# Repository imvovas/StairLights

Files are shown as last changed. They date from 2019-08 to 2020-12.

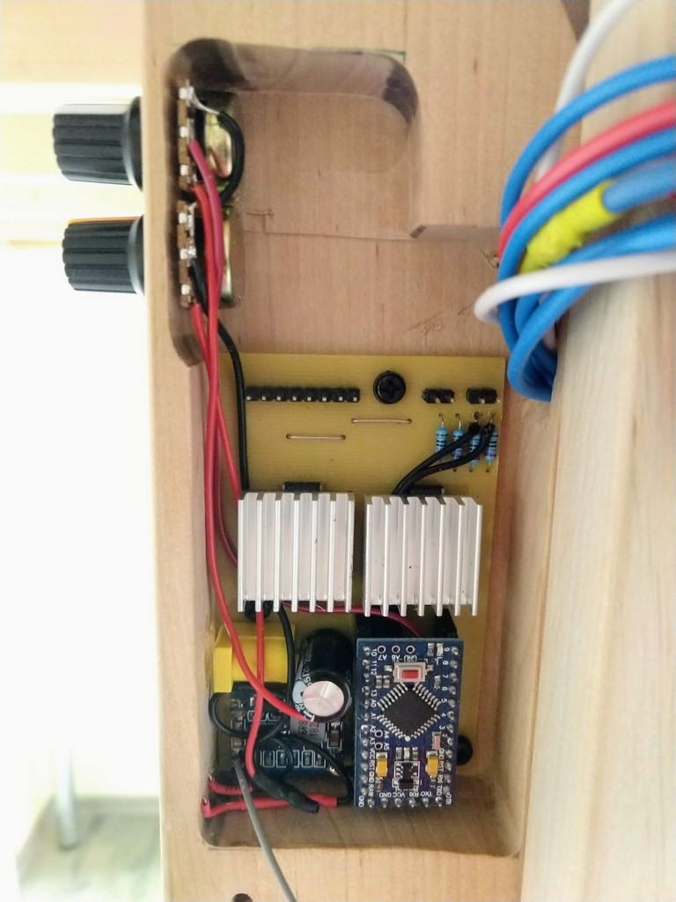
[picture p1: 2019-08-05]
photos/IMG_20190805_171643290.jpg

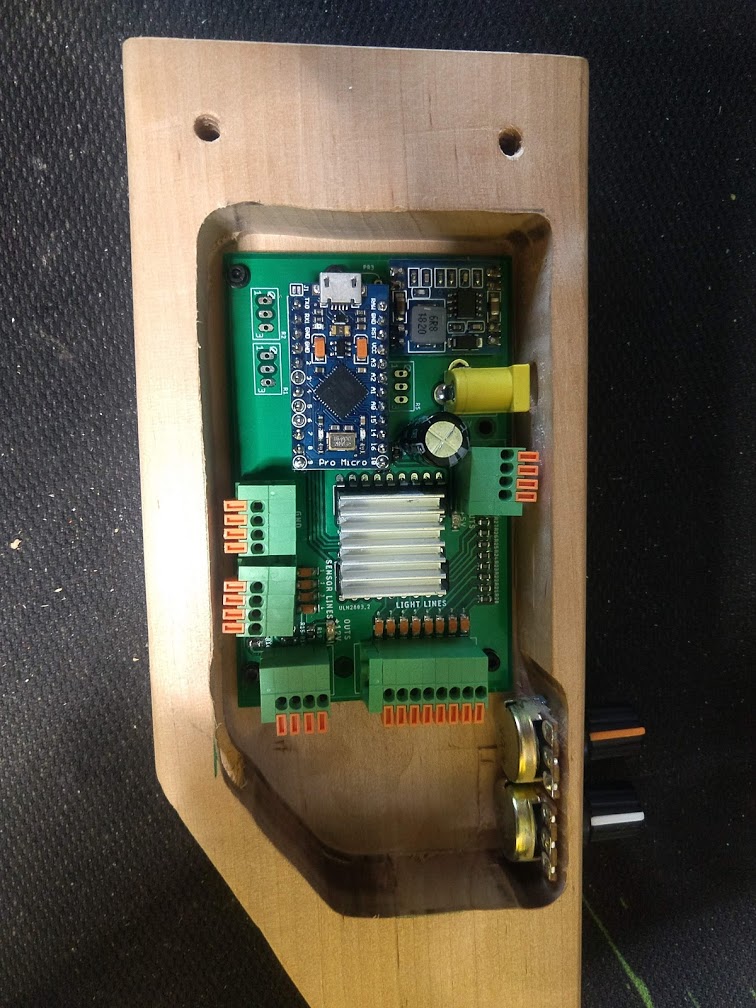
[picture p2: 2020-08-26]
photos/IMG_20200605_162837058.jpg

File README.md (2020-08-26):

# StairLights
Програмно-аппаратный комплект StairLights

Код для управления Arduino Leonardo (китайский клон)

В коде прошивки добавлены:
* управление скоростью отработки эффектов через подстроечный резистор;
* удалена поддержка кнопок вместе с библиотекой подавления дребезга;
* исправлены ошибки в визуальных эффектах.

Аппаратная часть находится в папке /Board. Актуальная версия платы в архиве StairLights_clips_2020-08-26.zip.
В актуальной редакции платы добавлены:
* дополнительные выводы 12 Вольт, 5 Вольт;
* добавлено два входа для сенсоров;
* добавлены отладочные светодиоды.
* Плата переведена на двухсторонний монтаж и под фабричное изготовление.

Ограничения:
- Напряжение питания устройства - 12 Вольт.
- Для питания Arduino Leonardo (китайский клон) использован DC-DC преобразователь (7-24 Вольта - 5 Вольт).
- Управляющие выходы подключаются к 8 сегментам LED-ленты 12 Вольт и потребляемой мощностью не более 500 мА на один сегмент.
- Используются управляющие сигналы TTL-уровня, при отсутствии сигнала входы притянуты к "земле".
- В качестве сенсоров можно использовать любые датчики/выключатели при условия соблюдения TTL-уровней сигнала. В коде прошивки реализована логика с поддержкой двух входов из четырех.

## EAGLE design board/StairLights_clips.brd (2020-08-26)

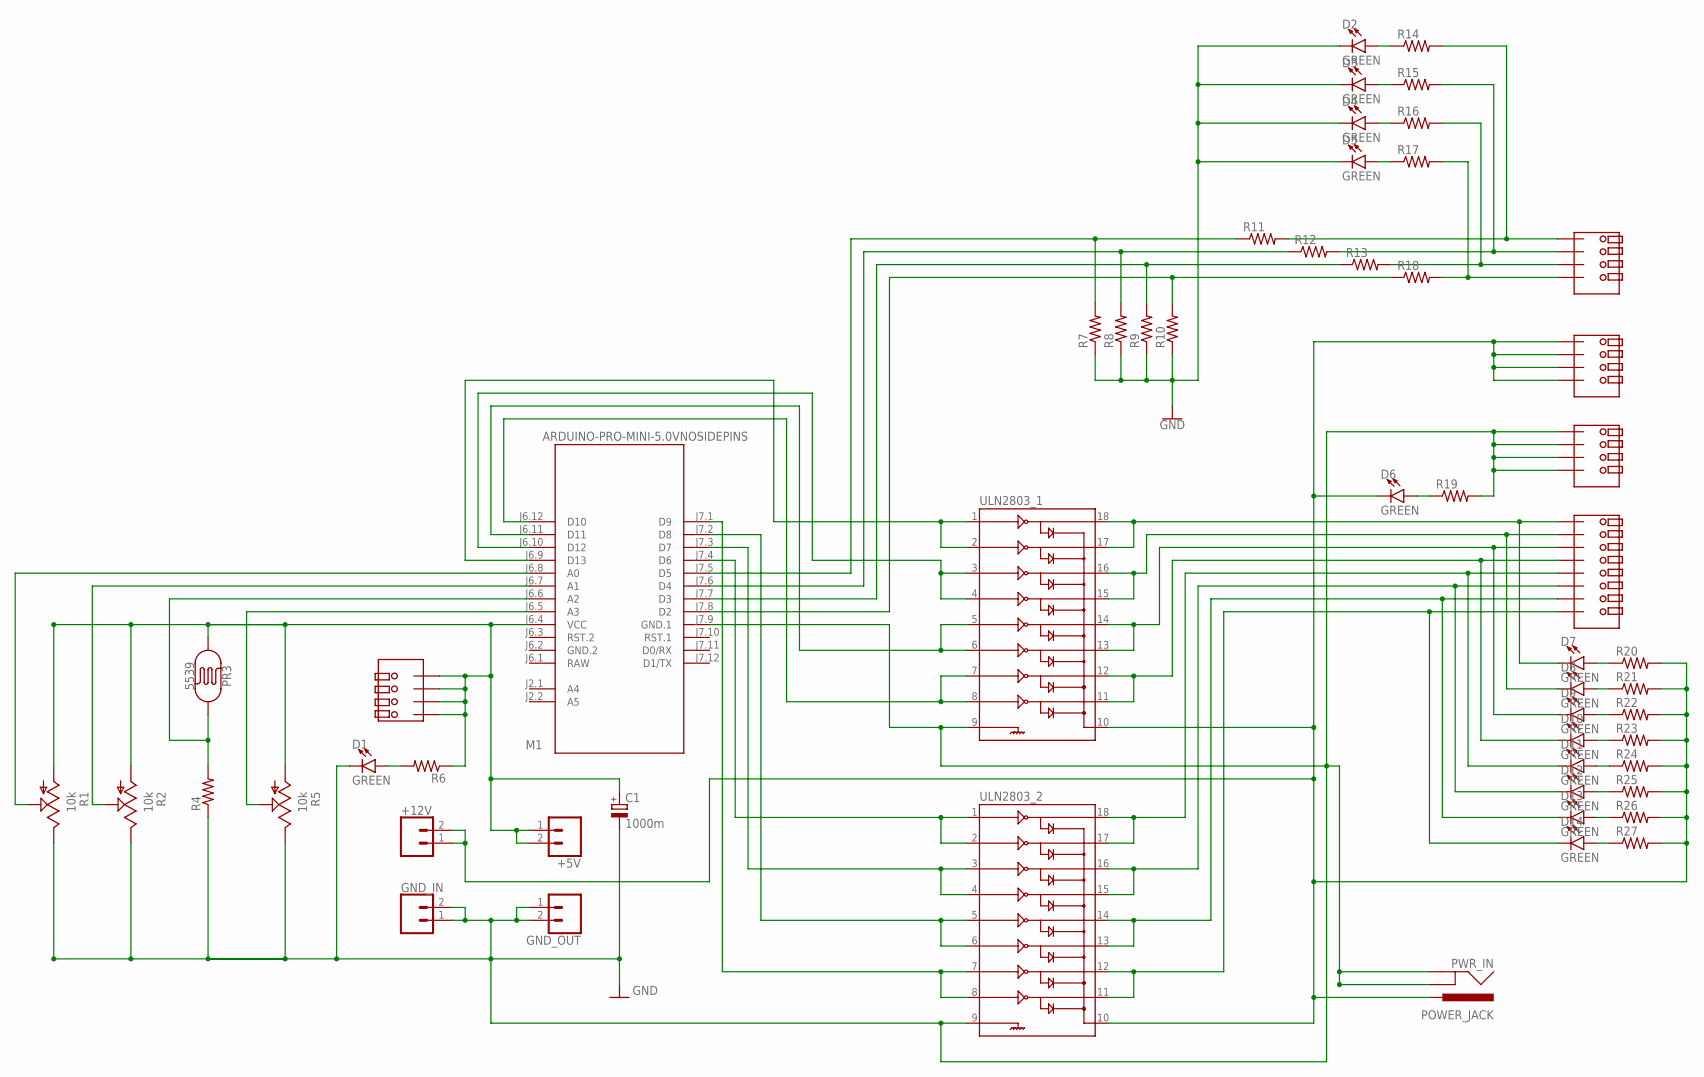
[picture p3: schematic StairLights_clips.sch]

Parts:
+5V, +12V: CONN_02; 1X02
C1: 1000m; E5-5
D1, D2, D3, D4, D5, D6, D7, D8, D9, D10, D11, D12, D13, D14: GREEN; LED-1206
GND_IN: CONN_02; 1X02
GND_OUT: CONN_02; 1X02
M1: ARDUINO-PRO-MINI-5.0VNOSIDEPINS; ARDUINO-PRO-MINI
PR3: 5539; PHOTOCELL
PWR_IN: POWER_JACK; POWER_JACK_PTH
R1, R2, R5: 10k; S64W
R4, R7, R8, R9, R10: 10k; R0805
R6, R11, R12, R13, R14, R15, R16, R17, R18, R19, R20, R21, R22, R23, R24, R25, R26, R27: 330; R0805
SC1, SC2, SC3, SC4: KF141V-4
SC5: KF141V-8
ULN2803_1, ULN2803_2: ULN2803DIP; DIL18

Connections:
GND: C1.-, D1.C, D2.C, D3.C, D4.C, D5.C, GND_IN.1, GND_IN.2, GND_OUT.1, GND_OUT.2, M1.J7.9 (GND.1), PWR_IN.GND, PWR_IN.GNDBREAK, R1.E, R2.E, R4.1, R5.E, R7.1, R8.1, R9.1, R10.1, R19.2, SC4.P$1, SC4.P$2, SC4.P$3, SC4.P$4, SC4.P$9, SC4.P$10, SC4.P$11, SC4.P$12, ULN2803_1.9, ULN2803_2.9
GND.2: M1.J6.2 (GND.2)
unnamed: D7.C, SC5.P$1, SC5.P$9, ULN2803_1.17, ULN2803_1.18
unnamed: D8.C, SC5.P$2, SC5.P$10, ULN2803_1.15, ULN2803_1.16
unnamed: M1.J7.7 (D3), R9.2, R13.1
unnamed: D9.C, SC5.P$3, SC5.P$11, ULN2803_1.13, ULN2803_1.14
unnamed: M1.J6.12 (D10), ULN2803_1.7, ULN2803_1.8
unnamed: D10.C, SC5.P$4, SC5.P$12, ULN2803_1.11, ULN2803_1.12
unnamed: M1.J6.6 (A2), PR3.2, R4.2
unnamed: D11.C, SC5.P$5, SC5.P$13, ULN2803_2.17, ULN2803_2.18
unnamed: D12.C, SC5.P$6, SC5.P$14, ULN2803_2.15, ULN2803_2.16
unnamed: M1.J6.11 (D11), ULN2803_1.5, ULN2803_1.6
unnamed: D13.C, SC5.P$7, SC5.P$15, ULN2803_2.13, ULN2803_2.14
unnamed: M1.J7.8 (D2), R10.2, R18.1
unnamed: M1.J7.3 (D7), ULN2803_2.3, ULN2803_2.4
unnamed: R13.2, R16.2, SC2.P$3, SC2.P$11
unnamed: M1.J6.5 (A3), R5.S
unnamed: D1.A, R6.2
unnamed: +5V.1, +5V.2, C1.+, M1.J6.4 (VCC), PR3.1, R1.A, R2.A, R5.A, R6.1, SC1.P$1, SC1.P$2, SC1.P$3, SC1.P$4, SC1.P$9, SC1.P$10, SC1.P$11, SC1.P$12
unnamed: D14.C, SC5.P$8, SC5.P$16, ULN2803_2.11, ULN2803_2.12
unnamed: R17.2, R18.2, SC2.P$4, SC2.P$12
unnamed: M1.J7.6 (D4), R8.2, R12.1
unnamed: M1.J7.1 (D9), ULN2803_2.7, ULN2803_2.8
unnamed: M1.J7.5 (D5), R7.2, R11.1
unnamed: R12.2, R15.2, SC2.P$2, SC2.P$10
unnamed: M1.J6.9 (D13), ULN2803_1.1, ULN2803_1.2
unnamed: R11.2, R14.2, SC2.P$1, SC2.P$9
unnamed: M1.J6.10 (D12), ULN2803_1.3, ULN2803_1.4
unnamed: M1.J6.7 (A1), R2.S
unnamed: M1.J6.8 (A0), R1.S
unnamed: M1.J7.4 (D6), ULN2803_2.1, ULN2803_2.2
unnamed: M1.J7.2 (D8), ULN2803_2.5, ULN2803_2.6
unnamed: D7.A, R20.1
unnamed: D8.A, R21.1
unnamed: D9.A, R22.1
unnamed: D10.A, R23.1
unnamed: D11.A, R24.1
unnamed: D12.A, R25.1
unnamed: D13.A, R26.1
unnamed: D14.A, R27.1
unnamed: +12V.1, +12V.2, D6.C, PWR_IN.PWR, R20.2, R21.2, R22.2, R23.2, R24.2, R25.2, R26.2, R27.2, SC3.P$1, SC3.P$2, SC3.P$3, SC3.P$4, SC3.P$9, SC3.P$10, SC3.P$11, SC3.P$12, ULN2803_1.10, ULN2803_2.10
unnamed: D6.A, R19.1
unnamed: D2.A, R14.1
unnamed: D3.A, R15.1
unnamed: D4.A, R16.1
unnamed: D5.A, R17.1
RAW: M1.J6.1 (RAW)

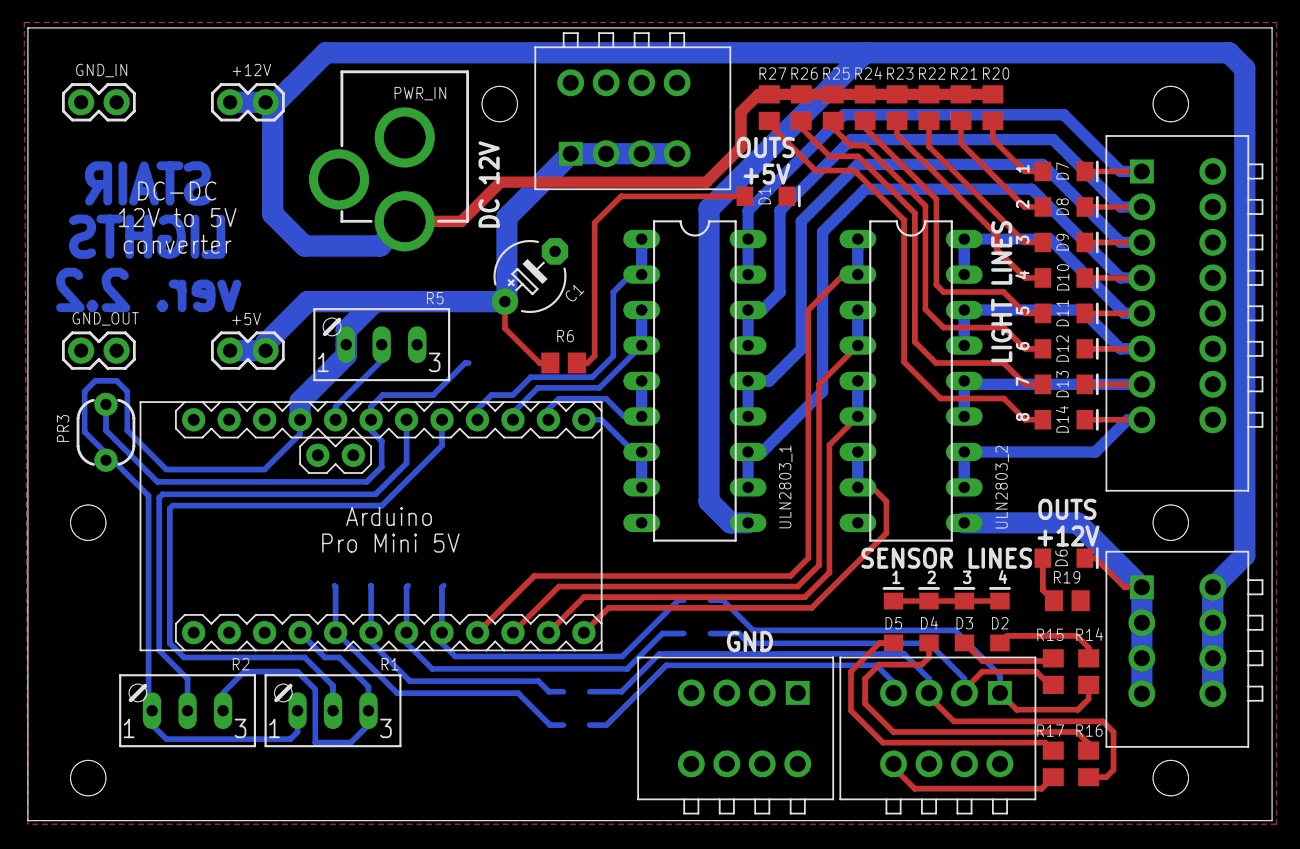
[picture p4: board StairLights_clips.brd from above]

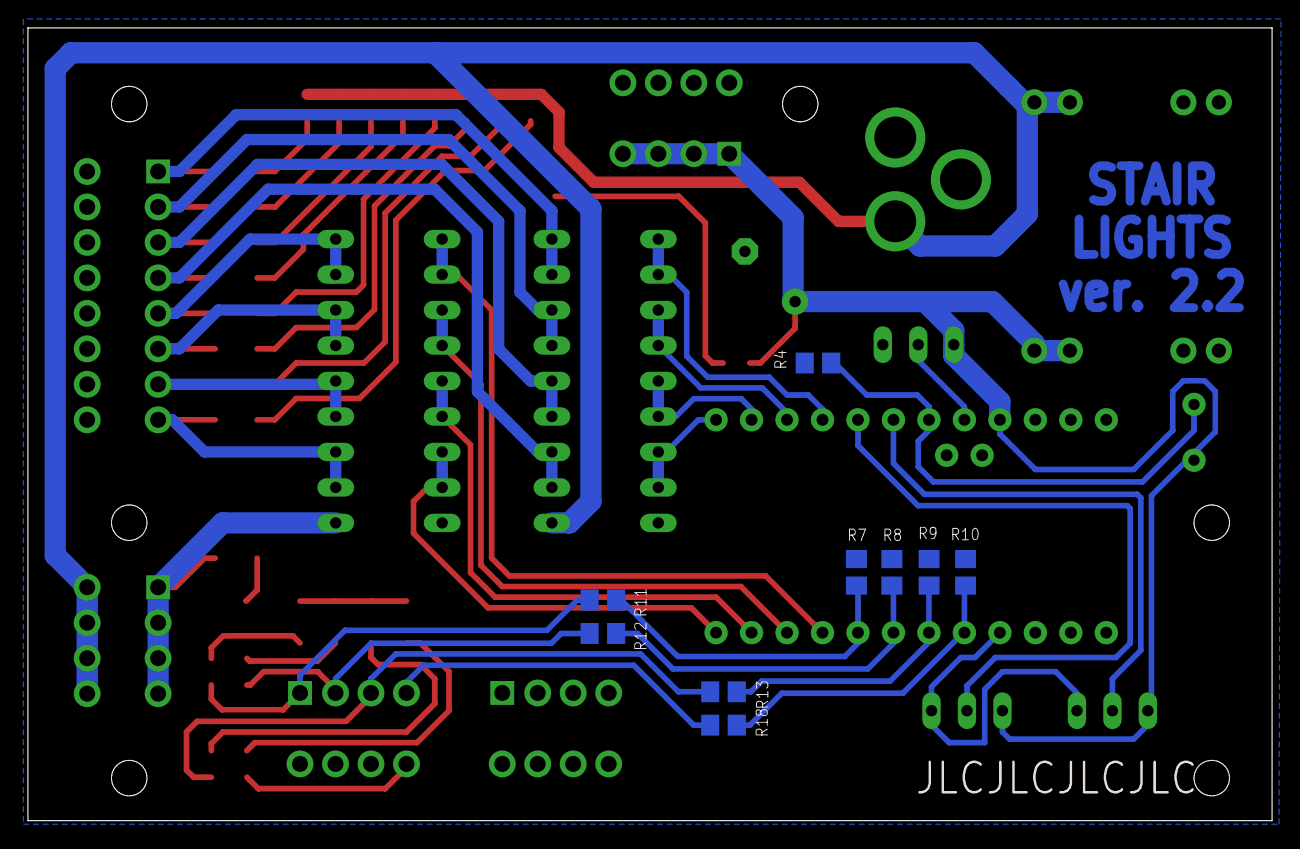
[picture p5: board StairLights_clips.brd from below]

Board: 2 copper layers, 89.1 x 56.8 mm, 55 parts (9 on the bottom side), 45 nets.

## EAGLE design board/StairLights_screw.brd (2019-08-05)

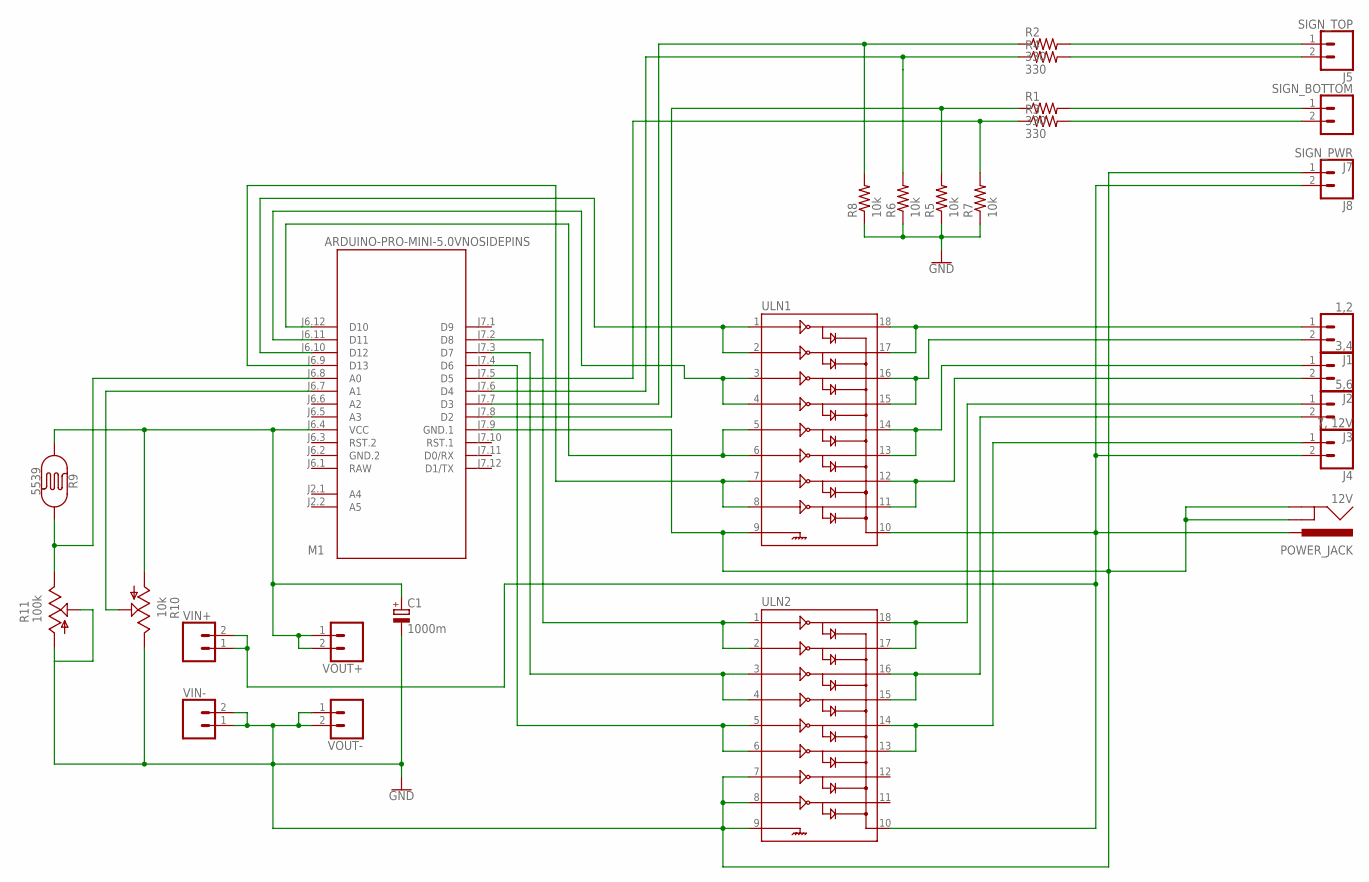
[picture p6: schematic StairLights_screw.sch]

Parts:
12V: POWER_JACK; POWER_JACK_PTH
C1: 1000m; E5-5
J1: 1,2; SCREWTERMINAL-5MM-2
J2: 3,4; SCREWTERMINAL-5MM-2
J3: 5,6; SCREWTERMINAL-5MM-2
J4: 7, 12V; SCREWTERMINAL-5MM-2
J5: SIGN_TOP; SCREWTERMINAL-5MM-2
J7: SIGN_BOTTOM; SCREWTERMINAL-5MM-2
J8: SIGN_PWR; SCREWTERMINAL-5MM-2
M1: ARDUINO-PRO-MINI-5.0VNOSIDEPINS; ARDUINO-PRO-MINI
R1, R2, R3, R4: 330; AXIAL-0.3
R5, R6, R7, R8: 10k; AXIAL-0.3
R9: 5539; PHOTOCELL
R10: 10k; S64W
R11: 100k; S64W
ULN1, ULN2: ULN2803DIP; DIL18
VIN+: CONN_02; 1X02
VIN-: CONN_02; 1X02
VOUT+: CONN_02; 1X02
VOUT-: CONN_02; 1X02

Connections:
GND: 12V.GND, 12V.GNDBREAK, C1.-, J8.1, M1.J7.9 (GND.1), R5.P$1 (1), R6.P$1 (1), R7.P$1 (1), R8.P$1 (1), R10.E, R11.A, R11.S, ULN1.9, ULN2.7, ULN2.8, ULN2.9, VIN-.1, VIN-.2, VOUT-.1, VOUT-.2
GND.2: M1.J6.2 (GND.2)
unnamed: J1.1, ULN1.17, ULN1.18
unnamed: J1.2, ULN1.15, ULN1.16
unnamed: M1.J7.7 (D3), R2.P$1 (1), R8.P$2 (2)
unnamed: J2.1, ULN1.13, ULN1.14
unnamed: M1.J6.12 (D10), ULN1.5, ULN1.6
unnamed: J2.2, ULN1.11, ULN1.12
unnamed: M1.J6.8 (A0), R9.2, R11.E
unnamed: J3.1, ULN2.17, ULN2.18
unnamed: J3.2, ULN2.15, ULN2.16
unnamed: M1.J6.10 (D12), ULN1.1, ULN1.2
unnamed: J4.1, ULN2.13, ULN2.14
unnamed: M1.J7.8 (D2), R1.P$1 (1), R5.P$2 (2)
unnamed: M1.J7.3 (D7), ULN2.3, ULN2.4
unnamed: M1.J7.4 (D6), ULN2.5, ULN2.6
unnamed: M1.J6.7 (A1), R10.S
unnamed: 12V.PWR, J4.2, J8.2, ULN1.10, ULN2.10, VIN+.1, VIN+.2
unnamed: C1.+, M1.J6.4 (VCC), R9.1, R10.A, VOUT+.1, VOUT+.2
unnamed: M1.J7.2 (D8), ULN2.1, ULN2.2
unnamed: M1.J7.6 (D4), R4.P$1 (1), R6.P$2 (2)
unnamed: M1.J7.5 (D5), R3.P$1 (1), R7.P$2 (2)
unnamed: J7.1, R1.P$2 (2)
unnamed: J7.2, R3.P$2 (2)
unnamed: M1.J6.9 (D13), ULN1.7, ULN1.8
unnamed: J5.2, R4.P$2 (2)
unnamed: J5.1, R2.P$2 (2)
unnamed: M1.J6.11 (D11), ULN1.3, ULN1.4
RAW: M1.J6.1 (RAW)

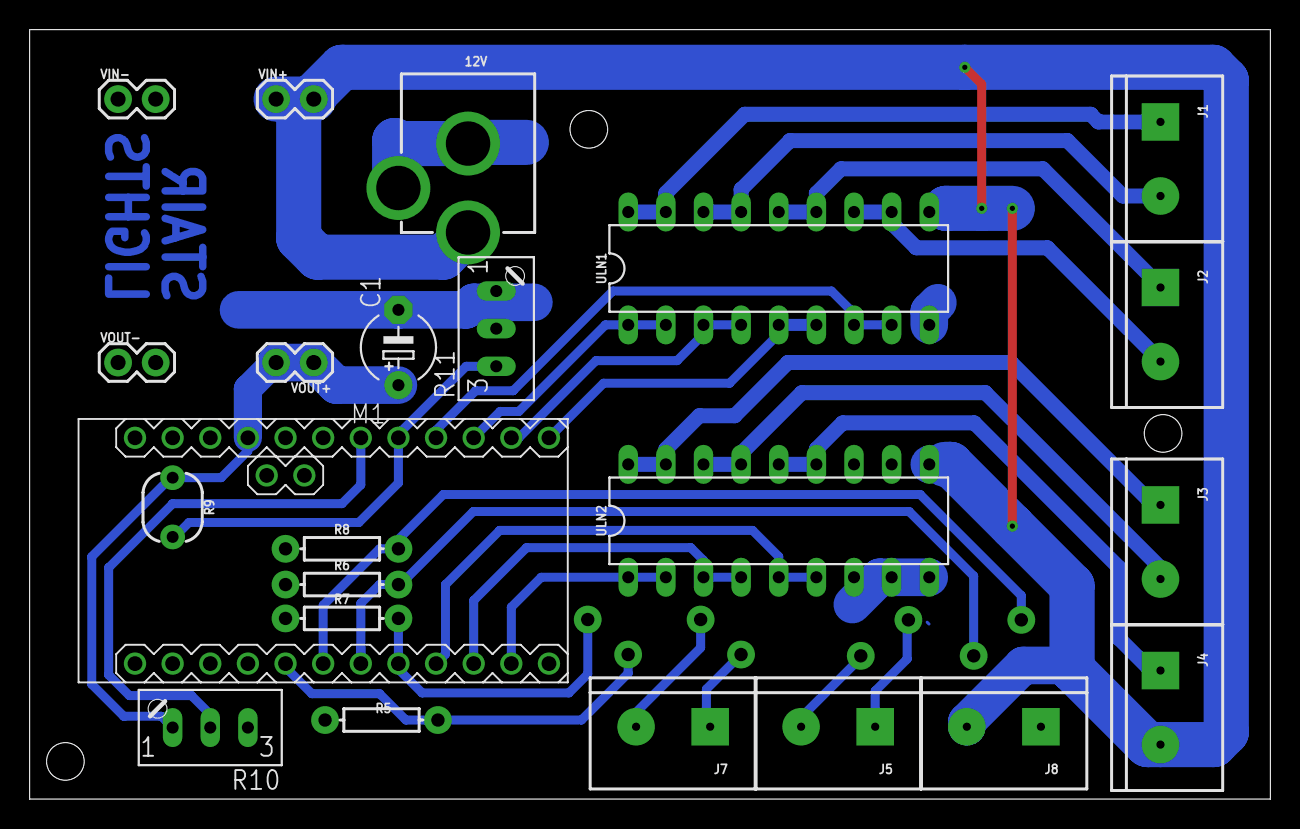
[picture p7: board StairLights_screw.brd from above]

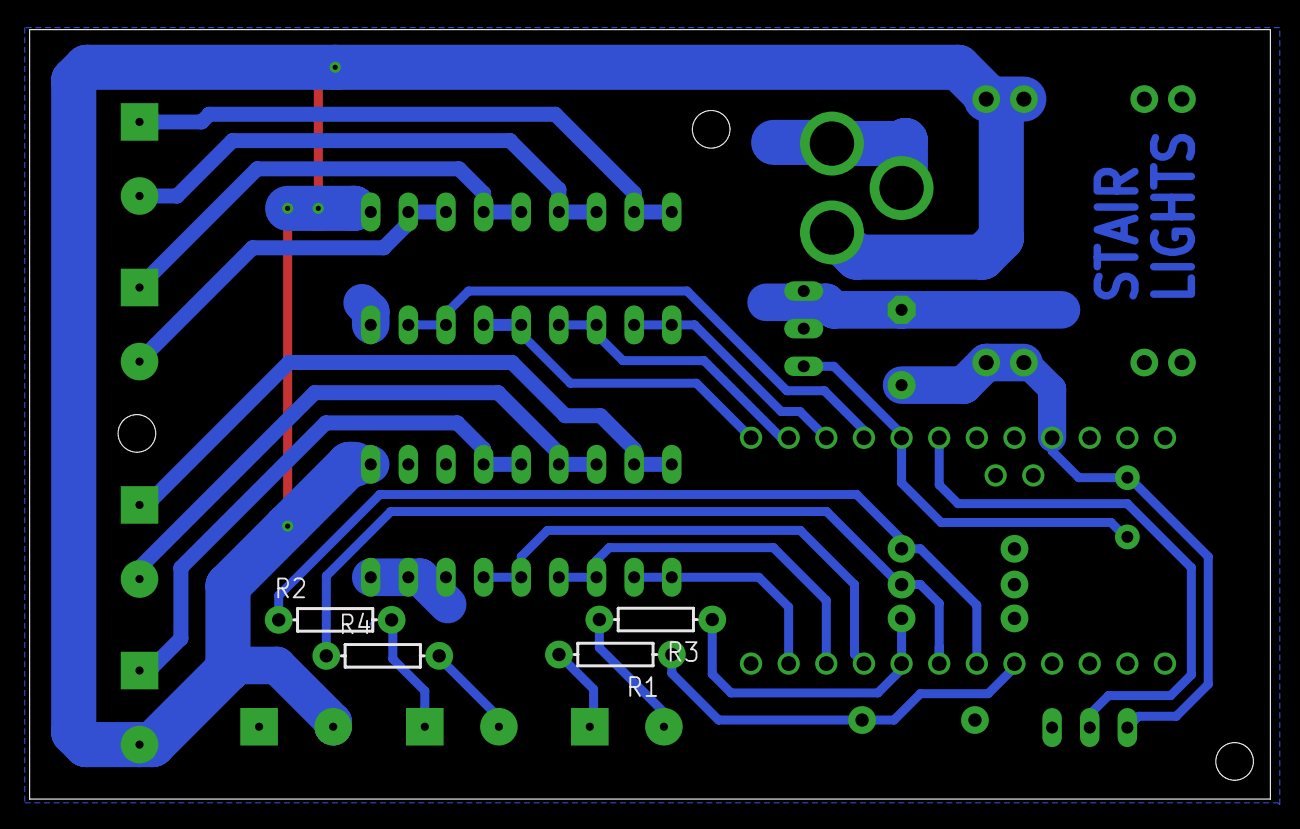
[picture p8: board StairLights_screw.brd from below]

Board: 2 copper layers, 83.7 x 51.9 mm, 27 parts (4 on the bottom side), 27 nets.

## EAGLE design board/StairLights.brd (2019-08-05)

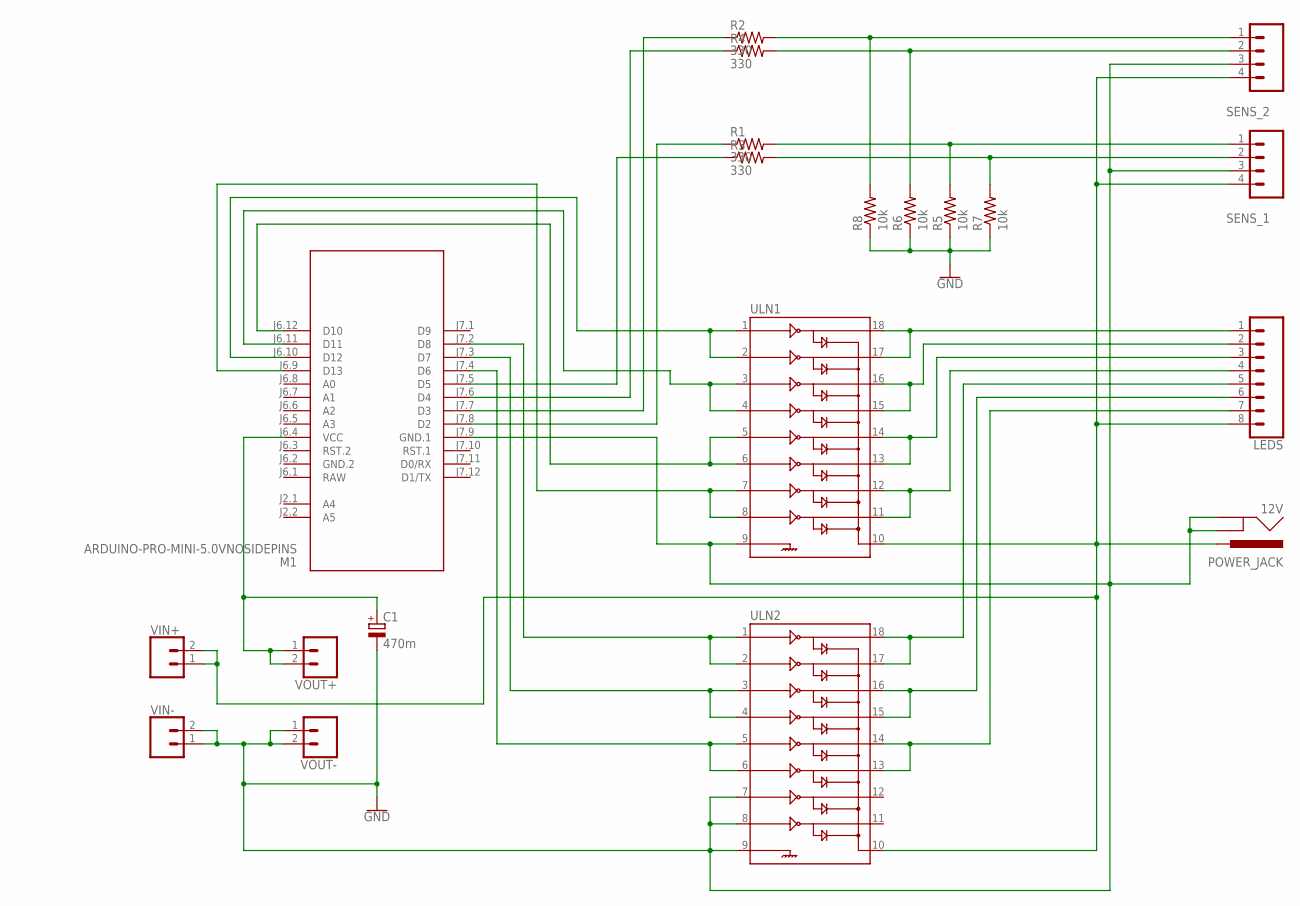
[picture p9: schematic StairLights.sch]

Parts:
12V: POWER_JACK; POWER_JACK_PTH
C1: 470m; E5-5
LEDS: CONN_08LONGPADS; 1X08_LONGPADS
M1: ARDUINO-PRO-MINI-5.0VNOSIDEPINS; ARDUINO-PRO-MINI
R1, R2, R3, R4: 330; AXIAL-0.3
R5, R6, R7, R8: 10k; AXIAL-0.3
SENS_1, SENS_2: CONN_04LONGPADS; 1X04_LONGPADS
ULN1, ULN2: ULN2803DIP; DIL18
VIN+: CONN_02; 1X02
VIN-: CONN_02; 1X02
VOUT+: CONN_02; 1X02
VOUT-: CONN_02; 1X02

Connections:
GND: 12V.GND, 12V.GNDBREAK, C1.-, M1.J7.9 (GND.1), R5.P$1 (1), R6.P$1 (1), R7.P$1 (1), R8.P$1 (1), SENS_1.3, SENS_2.3, ULN1.9, ULN2.7, ULN2.8, ULN2.9, VIN-.1, VIN-.2, VOUT-.1, VOUT-.2
GND.2: M1.J6.2 (GND.2)
unnamed: LEDS.1, ULN1.17, ULN1.18
unnamed: LEDS.2, ULN1.15, ULN1.16
unnamed: R2.P$2 (2), R8.P$2 (2), SENS_2.1
unnamed: LEDS.3, ULN1.13, ULN1.14
unnamed: M1.J6.12 (D10), ULN1.5, ULN1.6
unnamed: LEDS.4, ULN1.11, ULN1.12
unnamed: R4.P$2 (2), R6.P$2 (2), SENS_2.2
unnamed: LEDS.5, ULN2.17, ULN2.18
unnamed: LEDS.6, ULN2.15, ULN2.16
unnamed: M1.J6.10 (D12), ULN1.1, ULN1.2
unnamed: LEDS.7, ULN2.13, ULN2.14
unnamed: M1.J7.8 (D2), R1.P$1 (1)
unnamed: M1.J7.3 (D7), ULN2.3, ULN2.4
unnamed: M1.J7.4 (D6), ULN2.5, ULN2.6
unnamed: R1.P$2 (2), R5.P$2 (2), SENS_1.1
unnamed: 12V.PWR, LEDS.8, SENS_1.4, SENS_2.4, ULN1.10, ULN2.10, VIN+.1, VIN+.2
unnamed: C1.+, M1.J6.4 (VCC), VOUT+.1, VOUT+.2
unnamed: M1.J7.7 (D3), R2.P$1 (1)
unnamed: M1.J7.2 (D8), ULN2.1, ULN2.2
unnamed: M1.J7.6 (D4), R4.P$1 (1)
unnamed: R3.P$2 (2), R7.P$2 (2), SENS_1.2
unnamed: M1.J7.5 (D5), R3.P$1 (1)
unnamed: M1.J6.9 (D13), ULN1.7, ULN1.8
unnamed: M1.J6.11 (D11), ULN1.3, ULN1.4
RAW: M1.J6.1 (RAW)

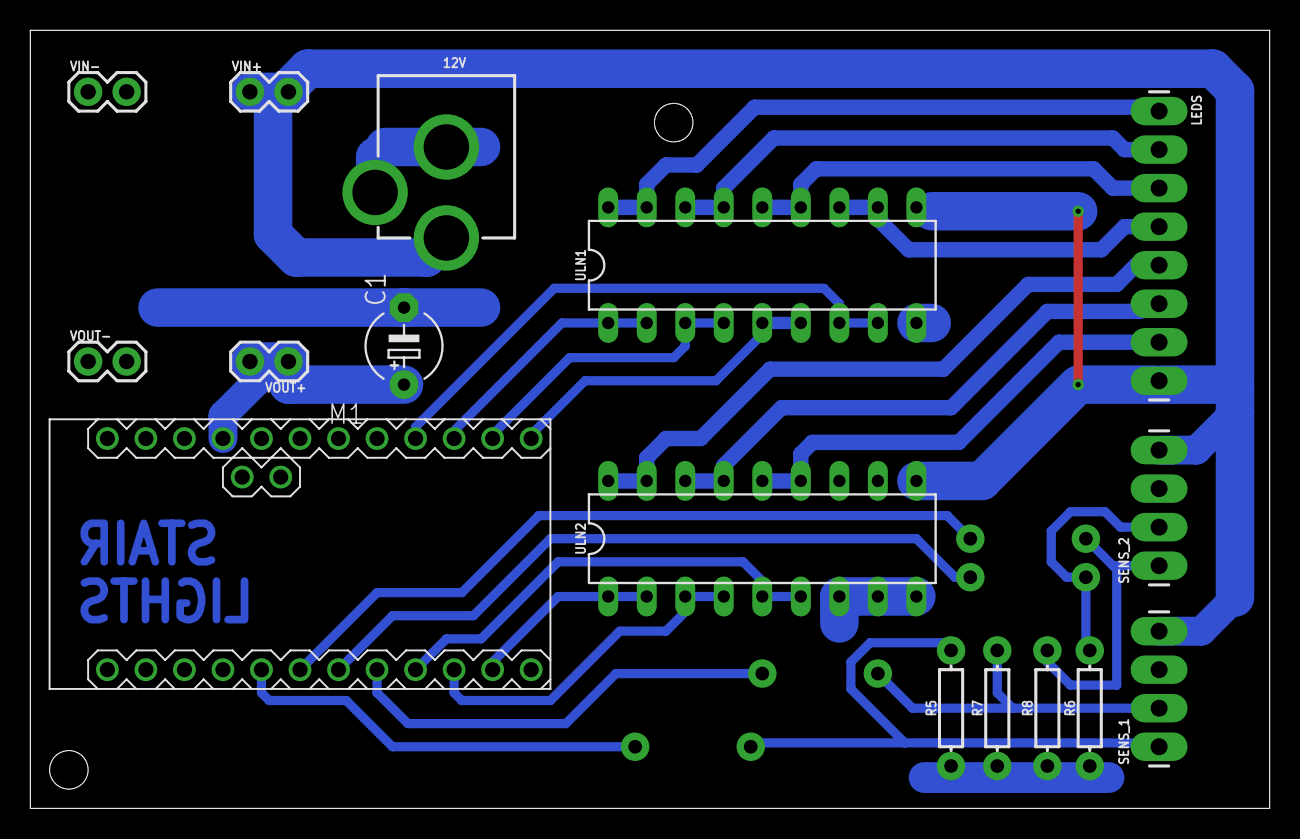
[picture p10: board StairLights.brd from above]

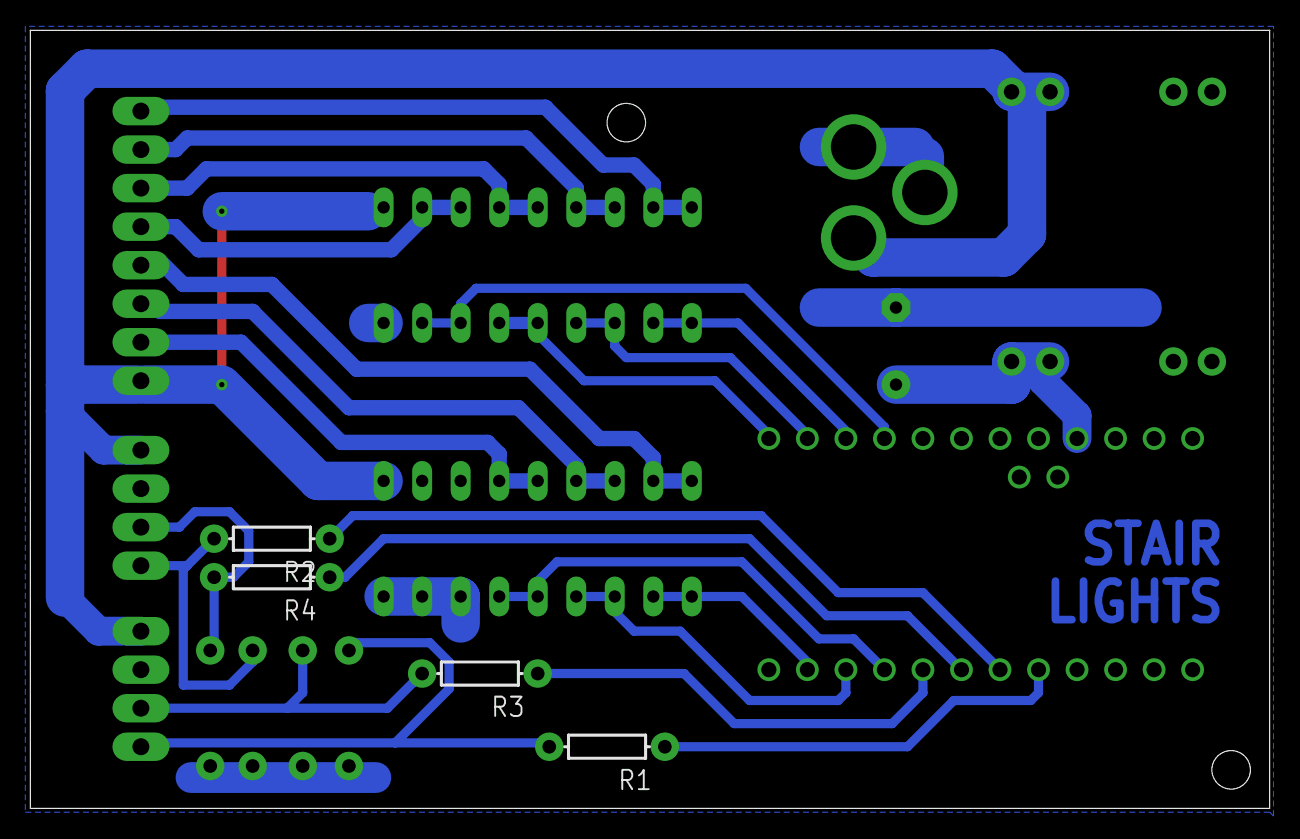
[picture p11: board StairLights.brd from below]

Board: 2 copper layers, 81.7 x 51.3 mm, 20 parts (4 on the bottom side), 25 nets.

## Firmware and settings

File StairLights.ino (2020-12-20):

/*
 * 
 * Программно-аппаратный модуль StairLights
 * (с) Vladimir Shvedchenko 
 * 
 * Version 2020.08.27.002
 * 
 */

#include <Chrono.h>  // добавляем несколько таймеров для управления событиями (http://github.com/SofaPirate/Chrono)
#include <SoftPWM.h> // для получения ШИМ (программного) на всех выходах (https://github.com/bhagman/SoftPWM)

const int lightMinBrightness = 0; // минимальная яркость свечения LED (0-255)
const int effectsVariants = 10; // количество вариантов гашения LED

const bool debug = false; // переменная, активирующая вывод отладочной информации в последовательный порт

/*
#if defined(ARDUINO_AVR_UNO) // устанавливаем номера управляющих выходов для Arduino UNO (тестовая плата)
  const int ledPin1 =  4; 
  const int ledPin2 =  5;
  const int ledPin3 =  6;
  const int ledPin4 =  7;
  const int ledPin5 =  8;
  const int ledPin6 =  9;
  const int ledPin7 =  10;

  const byte topSensorPin = 3; // устанавливаем номер входа от сенсора верхней части лестницы
  const byte bottomSensorPin = 2; // устанавливаем номер входа от сенсора нижней части лестницы

  int lightMinLuminosityLevelPin = A0; // аналоговый вход, куда подключен потенциометр для управления минимальной освещенностью
  int lightMaxBrightnessLevelPin = A1; // аналоговый вход, куда подключен потенциометр для управления максимальной яркостью свечения LED-ленты
  int luminositySensorPin = A2; // аналоговый вход, куда подключен фоторезистор
  int lightChangingSpeedPin = A3; // аналоговый вход, куда подключен потенциометр для управления скоростью работы эффектов

  const int lightDelay = 1000; // длительность включения LED для тестовой платы (1 сек)
#endif

#if defined(ARDUINO_AVR_PRO) // устанавливаем номера управляющих выходов для Arduino Pro Mini (продуктовая плата)
  const int ledPin1 =  12;
  const int ledPin2 =  11;
  const int ledPin3 =  10;
  const int ledPin4 =  13;
  const int ledPin5 =  8;
  const int ledPin6 =  7;
  const int ledPin7 =  6;

  const byte topSensorPin = 3; // устанавливаем номер входа от сенсора верхней части лестницы
  const byte bottomSensorPin = 2; // устанавливаем номер входа от сенсора нижней части лестницы

  int lightMinLuminosityLevelPin = A0; // аналоговый вход, куда подключен потенциометр для управления минимальной освещенностью
  int lightMaxBrightnessLevelPin = A1; // аналоговый вход, куда подключен потенциометр для управления максимальной яркостью свечения LED-ленты
  int luminositySensorPin = A2; // аналоговый вход, куда подключен фоторезистор
  int lightChangingSpeedPin = A3; // аналоговый вход, куда подключен потенциометр для управления скоростью работы эффектов

  const int lightDelay = 30000; // длительность включения LED для продуктовой платы (30 сек)
#endif
*/

#if defined(ARDUINO_AVR_LEONARDO) // устанавливаем номера управляющих выходов для Arduino Leonardo
  const int ledPin1 =  9;
  const int ledPin2 =  8;
  const int ledPin3 =  7;
  const int ledPin4 =  6;
  const int ledPin5 =  10;
  const int ledPin6 =  16;
  const int ledPin7 =  14;
  const int ledPin8 =  15;

  const byte topSensorPin = 5; // устанавливаем номер входа от сенсора верхней части лестницы
  const byte bottomSensorPin = 4; // устанавливаем номер входа от сенсора нижней части лестницы

  int lightMinLuminosityLevelPin = A0; // аналоговый вход, куда подключен потенциометр для управления минимальной освещенностью
  int lightMaxBrightnessLevelPin = A1; // аналоговый вход, куда подключен потенциометр для управления максимальной яркостью свечения LED-ленты
  int luminositySensorPin = A2; // аналоговый вход, куда подключен фоторезистор
  int lightChangingSpeedPin = A3; // аналоговый вход, куда подключен потенциометр для управления скоростью работы эффектов

  const int lightDelay = 30000; // длительность включения LED для продуктовой платы (30 сек)
#endif


int lightOnDelay = 100; // задержка между включениями LED
int lightOffDelay = 1000; // задержка между выключениями LED

int lightMinLuminosity = 0; // значение минимального уровня освещения, после которого включается освещение
int lightChangingSpeed = 125; // значение для скорости отработки эффектов
int lightMaxBrightness = 125; // максимальная яркость свечения LED (0-255), временное значение до чтения уровня заданного потенциометром на lightMaxBrightnessLevelPin
int luminositySensorValue = 0; // переменная для хранения считанного сенсором освещенности значения

bool luminositySensorLock = false; // признак блокировки реакции на сенсор освещенности (необходимо для продления действия подсветки, если сенсор засвечивается ей же)

int valueTopSensorPin = LOW; // устанавливаем признак отсутствия срабатывания от сенсора верхней части лестницы
int valueBottomSensorPin = LOW; // устанавливаем признак отсутствия срабатывания от сенсора нижней части лестницы

Chrono chronoTop; // создаём объект таймера для событий сенсора верхней части лестницы
Chrono chronoBottom; // создаём объект таймера для событий сенсора нижней части лестницы 

bool cycleTopDone = true; // признак завершения цикла "включить-выключить" для LED при инициировании цикла с верхней части лестницы
bool cycleBottomDone = true; // признак завершения цикла "включить-выключить" для LED при инициировании цикла с нижней части лестницы


void setup() {
  if (debug) {  
    Serial.begin(57600);
  }
  
  SoftPWMBegin(); // инициализируем програмную эмуляцию ШИМ
  
  SoftPWMSet(ledPin1, lightMinBrightness); // устанавливаем на всех выводах для LED минимальный уровень свечения lightMinBrightness
  SoftPWMSet(ledPin2, lightMinBrightness);
  SoftPWMSet(ledPin3, lightMinBrightness);
  SoftPWMSet(ledPin4, lightMinBrightness);
  SoftPWMSet(ledPin5, lightMinBrightness);
  SoftPWMSet(ledPin6, lightMinBrightness);
  SoftPWMSet(ledPin7, lightMinBrightness);
  SoftPWMSet(ledPin8, lightMinBrightness);

  SoftPWMSetFadeTime(ledPin1, 100, 2500); // устанавливаем время перехода lightMinBrightness-lightMaxBrightness (включение) и время перехода lightMaxBrightness-lightMinBrightness (выключение) для всех выводов LED
  SoftPWMSetFadeTime(ledPin2, 100, 2500);
  SoftPWMSetFadeTime(ledPin3, 100, 2500);
  SoftPWMSetFadeTime(ledPin4, 100, 2500);
  SoftPWMSetFadeTime(ledPin5, 100, 2500);
  SoftPWMSetFadeTime(ledPin6, 100, 2500);
  SoftPWMSetFadeTime(ledPin7, 100, 2500);
  SoftPWMSetFadeTime(ledPin8, 100, 2500);

  pinMode(topSensorPin,INPUT); // устанавливаем режим работы входа для сигнала сенсора верхней части лестницы
  pinMode(bottomSensorPin,INPUT); // устанавливаем режим работы входа для сигнала сенсора нижней части лестницы

  randomSeed(analogRead(3)); // инициализируем генератор псевдо-случайных чисел, запуская его от текущего сигнала на аналоговом входе
}


void loop() {
  doSensorsRead(); // читаем состояние сенсоров
  doSomeLogic(); // выполняем логику управления LED
}


// чтение сенсоров
void doSensorsRead() {
  lightMinLuminosity = map(analogRead(lightMinLuminosityLevelPin), 0, 1023, 0, 150); // читаем значение минимального уровня освещения
  luminositySensorValue = map(analogRead(luminositySensorPin), 0, 1023, 0, 255); // читаем значение уровня освещенности сенсора
  lightMaxBrightness = map(analogRead(lightMaxBrightnessLevelPin), 0, 1023, 0, 250); // читаем значение максимальной допустимой яркости LED-ленты
  lightChangingSpeed = map(analogRead(lightChangingSpeedPin), 0, 1023, 0, 255); // читаем значение для скорости отработки эффектов

  lightOnDelay = lightChangingSpeed;
  lightOffDelay = lightChangingSpeed * 10;

  valueTopSensorPin = digitalRead(topSensorPin); // читаем состояние сенсора верхней части лестницы
  valueBottomSensorPin = digitalRead(bottomSensorPin); // читаем состояние сенсора нижней части лестницы    
}


// управление логикой работы LED
void doSomeLogic() {
  if (((valueTopSensorPin == HIGH)&&(luminositySensorValue<lightMinLuminosity))||((valueTopSensorPin == HIGH)&&(luminositySensorLock == true))) { // если пришло событие от сенсора верхней части лестницы и уровень освещенности упал ниже luminosityLowValue
    switchOnTopLEDs(); // включаем LED в направлении сверху вниз
    cycleTopDone=false; // устанавливаем признак срабатывания от сенсора верхней части лестницы
    chronoTop.restart(); // перезапускаем таймер для событий верхней части лестницы
  }

  if (((valueBottomSensorPin == HIGH)&&(luminositySensorValue<lightMinLuminosity))||((valueBottomSensorPin == HIGH)&&(luminositySensorLock == true))) { // если пришло событие от сенсора нижней части лестницы и уровень освещенности упал ниже luminosityLowValue
    switchOnBottomLEDs(); // включаем LED в направлении снизу вверх
    cycleBottomDone=false; // устанавливаем признак срабатывания от сенсора нижней части лестницы
    chronoBottom.restart(); // перезапускаем таймер для событий нижней части лестницы
  }  

  if (chronoTop.hasPassed(lightDelay)&&(cycleTopDone==false)) { // если сработал таймер события с верхней части лестницы и у нас активен признак срабатывания верхней части лестницы
    cycleTopDone=true; // устанавливаем признак завершенности цикла "включить-выключить" для LED, при инициировании цикла с верхней части лестницы
    chronoTop.restart(); // перезапускаем таймер для событий верхней части лестницы
    switchOffTopLEDs(random(effectsVariants)); // выключаем LED в направлении сверху вниз по случайному сценарию
  }
  
  if (chronoBottom.hasPassed(lightDelay)&&(cycleBottomDone==false)) { // если сработал таймер события с нижней части лестницы и у нас активен признак срабатывания нижней части лестницы
    cycleBottomDone=true; // устанавливаем признак завершенности цикла "включить-выключить" для LED, при инициировании цикла с нижней части лестницы
    chronoBottom.restart(); // перезапускаем таймер для событий нижней части лестницы
    switchOffBottomLEDs(random(effectsVariants)); // выключаем LED в направлении снизу вверх по случайному сценарию
  }

  if (debug) {
    Serial.print("lightMinLuminosity: ");
    Serial.println(lightMinLuminosity);
    Serial.print("luminositySensorValue: ");
    Serial.println(luminositySensorValue);
    Serial.println();
    Serial.print("lightMaxBrightness: ");
    Serial.println(lightMaxBrightness);
    Serial.print("lightChangingSpeed: ");
    Serial.println(lightChangingSpeed);
    Serial.println();
    Serial.print("valueTopSensorPin: ");
    Serial.println(valueTopSensorPin);
    Serial.print("valueBottomSensorPin: ");
    Serial.println(valueBottomSensorPin);
    Serial.println("==============================");

    delay(1000);
  }
}

// включаем LED в направлении сверху вниз
void switchOnTopLEDs() {
    luminositySensorLock=true; // блокируем реакцию на уровень освещения    

    SoftPWMSet(ledPin1, lightMaxBrightness);
    delay(lightOnDelay);
    SoftPWMSet(ledPin2, lightMaxBrightness);
    delay(lightOnDelay);
    SoftPWMSet(ledPin3, lightMaxBrightness);
    delay(lightOnDelay);
    SoftPWMSet(ledPin4, lightMaxBrightness);
    delay(lightOnDelay);
    SoftPWMSet(ledPin5, lightMaxBrightness);
    delay(lightOnDelay);
    SoftPWMSet(ledPin6, lightMaxBrightness);
    delay(lightOnDelay);
    SoftPWMSet(ledPin7, lightMaxBrightness);    
    delay(lightOnDelay);
    SoftPWMSet(ledPin8, lightMaxBrightness);    
    delay(lightOnDelay);
}  

// включаем LED в направлении снизу вверх
void switchOnBottomLEDs() {
    luminositySensorLock=true; // блокируем реакцию на уровень освещения    

    SoftPWMSet(ledPin8, lightMaxBrightness);
    delay(lightOnDelay);
    SoftPWMSet(ledPin7, lightMaxBrightness);
    delay(lightOnDelay);
    SoftPWMSet(ledPin6, lightMaxBrightness);
    delay(lightOnDelay);
    SoftPWMSet(ledPin5, lightMaxBrightness);
    delay(lightOnDelay);
    SoftPWMSet(ledPin4, lightMaxBrightness);
    delay(lightOnDelay);
    SoftPWMSet(ledPin3, lightMaxBrightness);
    delay(lightOnDelay);
    SoftPWMSet(ledPin2, lightMaxBrightness);
    delay(lightOnDelay);
    SoftPWMSet(ledPin1, lightMaxBrightness);    
    delay(lightOnDelay);
}

// выключаем LED в направлении сверху вниз в соответствии с выбранным сценарием effectVariant
void switchOffTopLEDs(int effectVariant) {
  switch (effectVariant) {
    case 1: {
      SoftPWMSet(ledPin1, lightMinBrightness);
      SoftPWMSet(ledPin2, lightMinBrightness);
      SoftPWMSet(ledPin3, lightMinBrightness);
      SoftPWMSet(ledPin4, lightMinBrightness);
      SoftPWMSet(ledPin5, lightMinBrightness);
      SoftPWMSet(ledPin6, lightMinBrightness);
      SoftPWMSet(ledPin7, lightMinBrightness);
      SoftPWMSet(ledPin8, lightMinBrightness);
      break;
    }
    case 2: {  
      SoftPWMSet(ledPin1, lightMinBrightness);
      SoftPWMSet(ledPin3, lightMinBrightness);
      SoftPWMSet(ledPin5, lightMinBrightness);
      SoftPWMSet(ledPin7, lightMinBrightness);
      delay(lightOffDelay);
      SoftPWMSet(ledPin2, lightMinBrightness);
      SoftPWMSet(ledPin4, lightMinBrightness);
      SoftPWMSet(ledPin6, lightMinBrightness);
      SoftPWMSet(ledPin8, lightMinBrightness);
      delay(lightOffDelay);
      break;
    }
    case 3: {
      SoftPWMSet(ledPin2, lightMinBrightness);
      SoftPWMSet(ledPin4, lightMinBrightness);
      SoftPWMSet(ledPin6, lightMinBrightness);
      SoftPWMSet(ledPin8, lightMinBrightness);
      delay(lightOffDelay);      
      SoftPWMSet(ledPin1, lightMinBrightness);
      SoftPWMSet(ledPin3, lightMinBrightness);
      SoftPWMSet(ledPin5, lightMinBrightness);
      SoftPWMSet(ledPin7, lightMinBrightness);
      delay(lightOffDelay);
      break;
    }
    case 4: {
      SoftPWMSet(ledPin1, lightMinBrightness);
      delay(lightOffDelay);
      SoftPWMSet(ledPin2, lightMinBrightness);
      delay(lightOffDelay);
      SoftPWMSet(ledPin3, lightMinBrightness);
      delay(lightOffDelay);
      SoftPWMSet(ledPin4, lightMinBrightness);
      delay(lightOffDelay);
      SoftPWMSet(ledPin5, lightMinBrightness);
      delay(lightOffDelay);
      SoftPWMSet(ledPin6, lightMinBrightness);
      delay(lightOffDelay);
      SoftPWMSet(ledPin7, lightMinBrightness);
      delay(lightOffDelay);
      SoftPWMSet(ledPin8, lightMinBrightness);
      delay(lightOffDelay);
      break;
    }
    case 5: {
      SoftPWMSet(ledPin1, lightMinBrightness);
      SoftPWMSet(ledPin2, lightMinBrightness);
      delay(lightOffDelay);
      SoftPWMSet(ledPin3, lightMinBrightness);
      SoftPWMSet(ledPin4, lightMinBrightness);
      delay(lightOffDelay);
      SoftPWMSet(ledPin5, lightMinBrightness);
      SoftPWMSet(ledPin6, lightMinBrightness);
      delay(lightOffDelay);
      SoftPWMSet(ledPin7, lightMinBrightness);
      SoftPWMSet(ledPin8, lightMinBrightness);
      delay(lightOffDelay);
      break;
    }
    case 6: {
      SoftPWMSet(ledPin1, lightMinBrightness);
      delay(lightOffDelay);
      SoftPWMSet(ledPin3, lightMinBrightness);
      delay(lightOffDelay);
      SoftPWMSet(ledPin5, lightMinBrightness);
      delay(lightOffDelay);
      SoftPWMSet(ledPin7, lightMinBrightness);
      delay(lightOffDelay);
      SoftPWMSet(ledPin2, lightMinBrightness);
      delay(lightOffDelay);
      SoftPWMSet(ledPin4, lightMinBrightness);
      delay(lightOffDelay);
      SoftPWMSet(ledPin6, lightMinBrightness);
      delay(lightOffDelay);
      SoftPWMSet(ledPin8, lightMinBrightness);
      delay(lightOffDelay);
      break;
    }
    case 7: {
      SoftPWMSet(ledPin2, lightMinBrightness);
      delay(lightOffDelay);
      SoftPWMSet(ledPin4, lightMinBrightness);
      delay(lightOffDelay);
      SoftPWMSet(ledPin6, lightMinBrightness);
      delay(lightOffDelay);
      SoftPWMSet(ledPin8, lightMinBrightness);
      delay(lightOffDelay);
      SoftPWMSet(ledPin1, lightMinBrightness);
      delay(lightOffDelay);
      SoftPWMSet(ledPin3, lightMinBrightness);
      delay(lightOffDelay);
      SoftPWMSet(ledPin5, lightMinBrightness);
      delay(lightOffDelay);
      SoftPWMSet(ledPin7, lightMinBrightness);
      delay(lightOffDelay);
      break;
    }
    case 8: {
      SoftPWMSet(ledPin1, lightMinBrightness);
      delay(lightOffDelay);
      SoftPWMSet(ledPin8, lightMinBrightness);
      delay(lightOffDelay);
      SoftPWMSet(ledPin2, lightMinBrightness);
      delay(lightOffDelay);
      SoftPWMSet(ledPin7, lightMinBrightness);
      delay(lightOffDelay);
      SoftPWMSet(ledPin3, lightMinBrightness);
      delay(lightOffDelay);
      SoftPWMSet(ledPin6, lightMinBrightness);
      delay(lightOffDelay);
      SoftPWMSet(ledPin4, lightMinBrightness);
      delay(lightOffDelay);
      SoftPWMSet(ledPin5, lightMinBrightness);
      delay(lightOffDelay);
      break;
    }
    case 9: {
      SoftPWMSet(ledPin1, lightMinBrightness);
      SoftPWMSet(ledPin2, lightMinBrightness);
      delay(lightOffDelay);
      SoftPWMSet(ledPin7, lightMinBrightness);
      SoftPWMSet(ledPin8, lightMinBrightness);
      delay(lightOffDelay);
      SoftPWMSet(ledPin3, lightMinBrightness);
      SoftPWMSet(ledPin4, lightMinBrightness);
      delay(lightOffDelay);
      SoftPWMSet(ledPin5, lightMinBrightness);
      SoftPWMSet(ledPin6, lightMinBrightness);
      delay(lightOffDelay);      
      break;
    }    
    case 10: {
      SoftPWMSet(ledPin1, lightMinBrightness);
      SoftPWMSet(ledPin8, lightMinBrightness);
      delay(lightOffDelay);
      SoftPWMSet(ledPin2, lightMinBrightness);
      SoftPWMSet(ledPin7, lightMinBrightness);
      delay(lightOffDelay);
      SoftPWMSet(ledPin3, lightMinBrightness);
      SoftPWMSet(ledPin6, lightMinBrightness);
      delay(lightOffDelay);
      SoftPWMSet(ledPin4, lightMinBrightness);
      SoftPWMSet(ledPin5, lightMinBrightness);
      delay(lightOffDelay);      
      break;
    }
    default: {
      SoftPWMSet(ledPin1, lightMinBrightness);
      delay(lightOffDelay);
      SoftPWMSet(ledPin2, lightMinBrightness);
      delay(lightOffDelay);
      SoftPWMSet(ledPin3, lightMinBrightness);
      delay(lightOffDelay);
      SoftPWMSet(ledPin4, lightMinBrightness);
      delay(lightOffDelay);
      SoftPWMSet(ledPin5, lightMinBrightness);
      delay(lightOffDelay);
      SoftPWMSet(ledPin6, lightMinBrightness);
      delay(lightOffDelay);
      SoftPWMSet(ledPin7, lightMinBrightness);
      delay(lightOffDelay);
      SoftPWMSet(ledPin8, lightMinBrightness);
      delay(lightOffDelay);
      break;
    }
  }  
  luminositySensorLock = false; // разблокируем реакцию на уровень освещения
}
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

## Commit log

2019-08-05 Уточнения
2019-08-05 Исправлена ошибка с номиналом потенциометра
    [StairLights_screw.brd, StairLights_screw.sch]
2019-08-19 Update StairLights.ino
    Косметические правки в начальных настройках.
2020-08-26 Version 2020.08.26.001
    Исправление ошибок, переделка платы и т.п.
    [StairLights_clips.brd, StairLights_clips.sch]
2020-08-27 Небольшие правки логики

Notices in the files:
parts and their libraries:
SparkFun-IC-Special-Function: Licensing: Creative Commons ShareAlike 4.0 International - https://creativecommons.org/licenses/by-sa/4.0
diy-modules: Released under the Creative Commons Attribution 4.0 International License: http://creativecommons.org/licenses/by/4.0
